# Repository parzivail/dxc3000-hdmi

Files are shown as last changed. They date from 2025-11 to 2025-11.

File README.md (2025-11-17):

# Sony DXC-3000A HDMI Conversion

This repository is split into multiple KiCad projects.

## MS9282 breakout

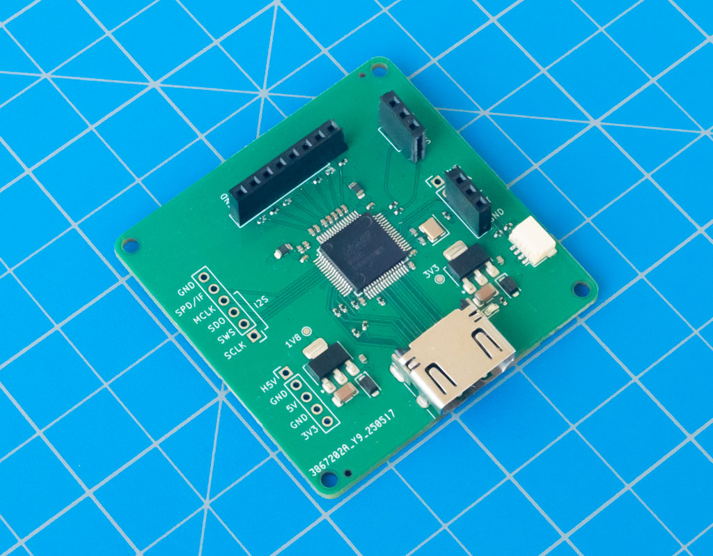
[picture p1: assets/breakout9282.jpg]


Contains the MS9282 breakout

Directory: `ms9282_carrier`

## DXC-3000A module template

Contains the blank PCB that matches the physical dimensions and 50-pin header of the backplane modules

Directory: `module_template`

## DXC-3000A module breakout

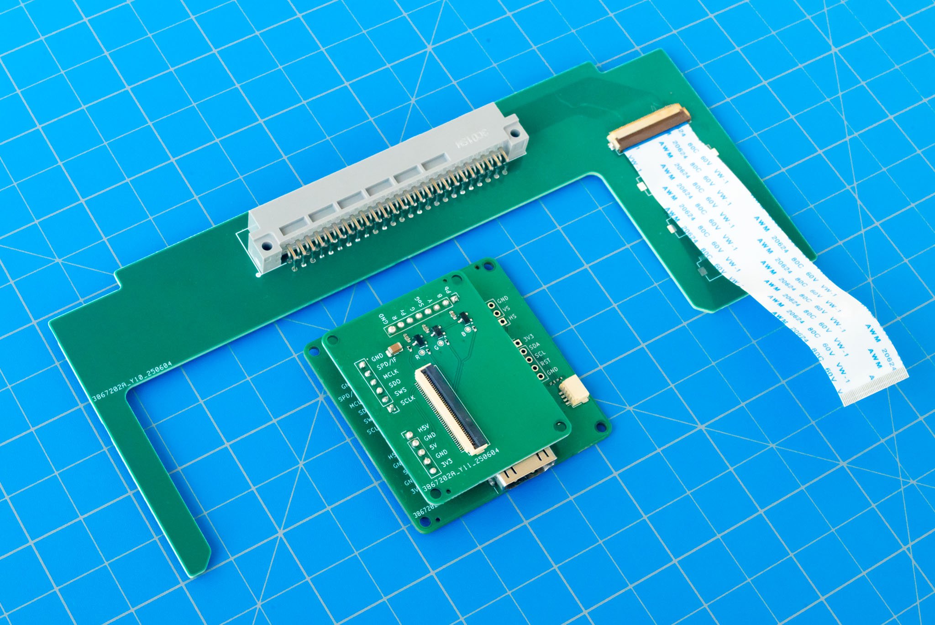
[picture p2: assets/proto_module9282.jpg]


A few assets in this image:

The DXC-3000A backplane-to-FPC breakout board
* Directory: `module_breakout`

The video conditioner "shield" for the MS9282 breakout
* Directory: `ms9282_carrier_adapter`

Pairs with the MS9282 breakout from above.

## MS9282 module

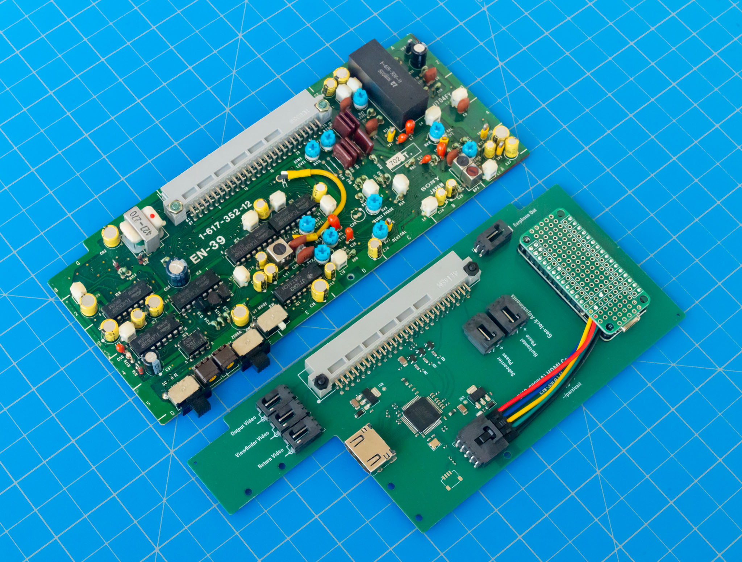
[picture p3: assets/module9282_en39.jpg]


Contains the complete MS9282-based EN-39 substitute for HDMI conversion. The image shows it in comparison with the original EN-39 module.

Directory: `ms9282_module`

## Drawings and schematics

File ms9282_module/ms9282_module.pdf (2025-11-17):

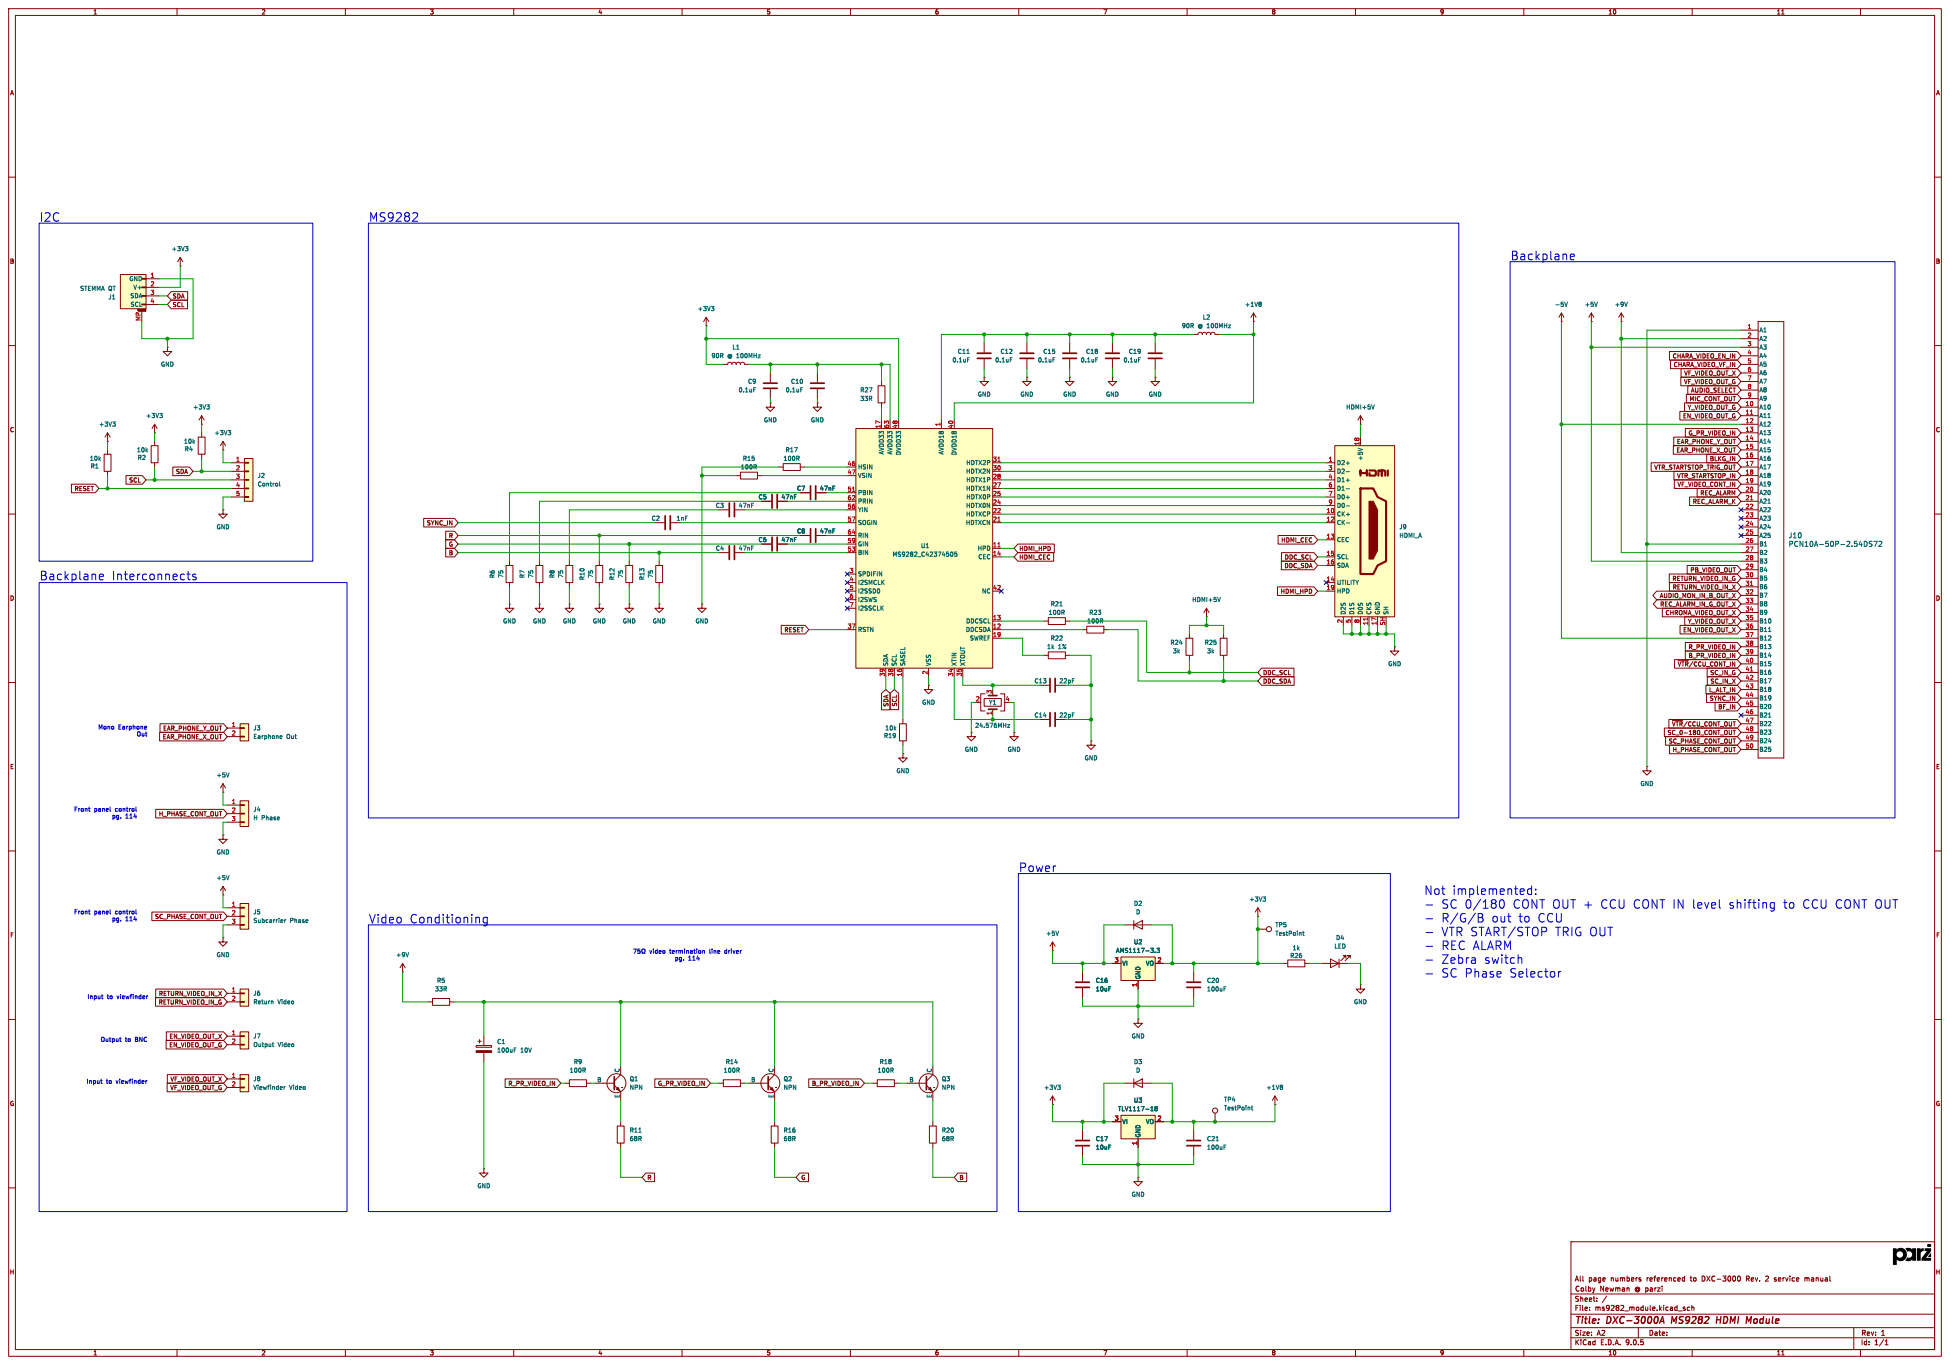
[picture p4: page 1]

1 XTIN 34 XTOUT 35 DDCSCL 13 DDCSDA 12 U1 MS9282_C42374505 C7 47nF C8 47nF R27

2 DVDD18 40 HDTX2P 31 HDTX2N 30 HDTX1P 28 HDTX1N 27 HDTX0P 25 HDTX0N 24 HDTXCP 22 HDTXCN 21 HPD 11 CEC 14 NC 42 SWREF 19 HSIN 46 VSIN 47 SOGIN 57

8 CKS 11 GND 17 SH SH

Mono Earphone Out Output to BNC

Front panel control pg. 114

- VTR START/STOP TRIG OUT
- REC ALARM
- Zebra switch
- SC Phase Selector

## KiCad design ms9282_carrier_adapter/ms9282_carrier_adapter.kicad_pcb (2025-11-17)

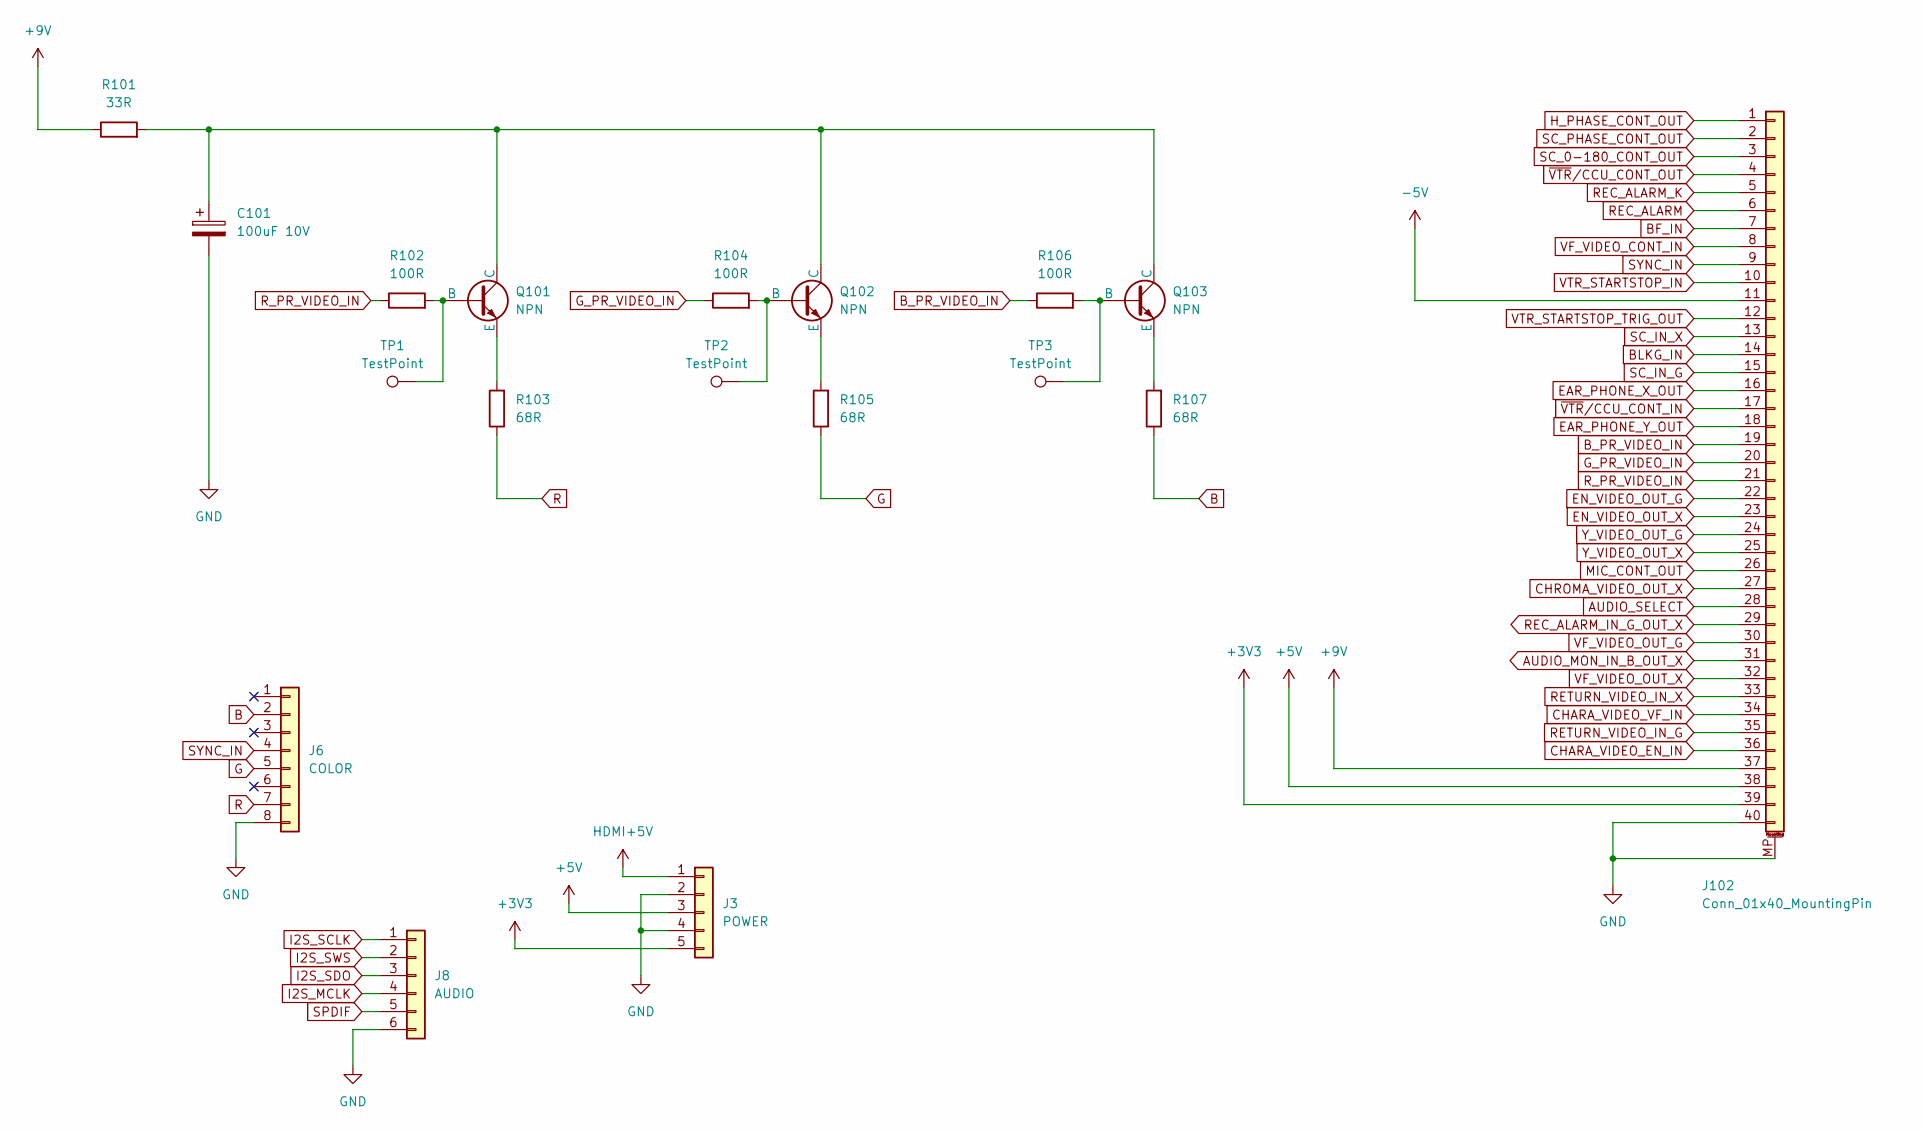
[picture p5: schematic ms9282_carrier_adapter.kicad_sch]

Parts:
C101: 100uF 10V; C_1206_3216Metric; LCSC Part C15008
J3: POWER; PinHeader_1x05_P2.54mm_Vertical
J6: COLOR; PinHeader_1x08_P2.54mm_Vertical
J8: AUDIO; PinHeader_1x06_P2.54mm_Vertical
J102: Conn_01x40_MountingPin; Hirose_FH12-40S-0.5SH_1x40-1MP_P0.50mm_Horizontal; LCSC Part C596725
Q101, Q102, Q103: NPN; SOT-23; LCSC Part C27829
R101: 33R; R_0402_1005Metric; LCSC Part C25105
R102, R104, R106: 100R; R_0402_1005Metric; LCSC Part C25076
R103, R105, R107: 68R; R_0603_1608Metric; LCSC Part C27592
TP1, TP2, TP3: TestPoint; TestPoint_Pad_D1.0mm

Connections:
+3V3: J3.5, J102.39
+5V: J3.3, J102.38
+9V: J102.37, R101.1
-5V: J102.11
AUDIO_MON_IN_B_OUT_X: J102.31
AUDIO_SELECT: J102.28
B: J6.2, R107.1
BF_IN: J102.7
BLKG_IN: J102.14
B_PR_VIDEO_IN: J102.19, R106.1
CHARA_VIDEO_EN_IN: J102.36
CHARA_VIDEO_VF_IN: J102.34
CHROMA_VIDEO_OUT_X: J102.27
EAR_PHONE_X_OUT: J102.16
EAR_PHONE_Y_OUT: J102.18
EN_VIDEO_OUT_G: J102.22
EN_VIDEO_OUT_X: J102.23
G: J6.5, R105.1
GND: C101.2, J3.2, J3.4, J6.8, J8.6, J102.40, J102.MP (MountPin)
G_PR_VIDEO_IN: J102.20, R104.1
HDMI+5V: J3.1
H_PHASE_CONT_OUT: J102.1
I2S_MCLK: J8.4
I2S_SCLK: J8.1
I2S_SDO: J8.3
I2S_SWS: J8.2
MIC_CONT_OUT: J102.26
unnamed: Q101.1 (B), R102.2, TP1.1
unnamed: C101.1, Q101.3 (C), Q102.3 (C), Q103.3 (C), R101.2
unnamed: Q101.2 (E), R103.2
unnamed: Q102.1 (B), R104.2, TP2.1
unnamed: Q102.2 (E), R105.2
unnamed: Q103.1 (B), R106.2, TP3.1
unnamed: Q103.2 (E), R107.2
R: J6.7, R103.1
REC_ALARM: J102.6
REC_ALARM_IN_G_OUT_X: J102.29
REC_ALARM_K: J102.5
RETURN_VIDEO_IN_G: J102.35
RETURN_VIDEO_IN_X: J102.33
R_PR_VIDEO_IN: J102.21, R102.1
SC_0-180_CONT_OUT: J102.3
SC_IN_G: J102.15
SC_IN_X: J102.13
SC_PHASE_CONT_OUT: J102.2
SPDIF: J8.5
SYNC_IN: J6.4, J102.9
VF_VIDEO_CONT_IN: J102.8
VF_VIDEO_OUT_G: J102.30
VF_VIDEO_OUT_X: J102.32
VTR_STARTSTOP_IN: J102.10
VTR_STARTSTOP_TRIG_OUT: J102.12
Y_VIDEO_OUT_G: J102.24
Y_VIDEO_OUT_X: J102.25
~VTR/CCU_CONT_IN: J102.17
~VTR/CCU_CONT_OUT: J102.4

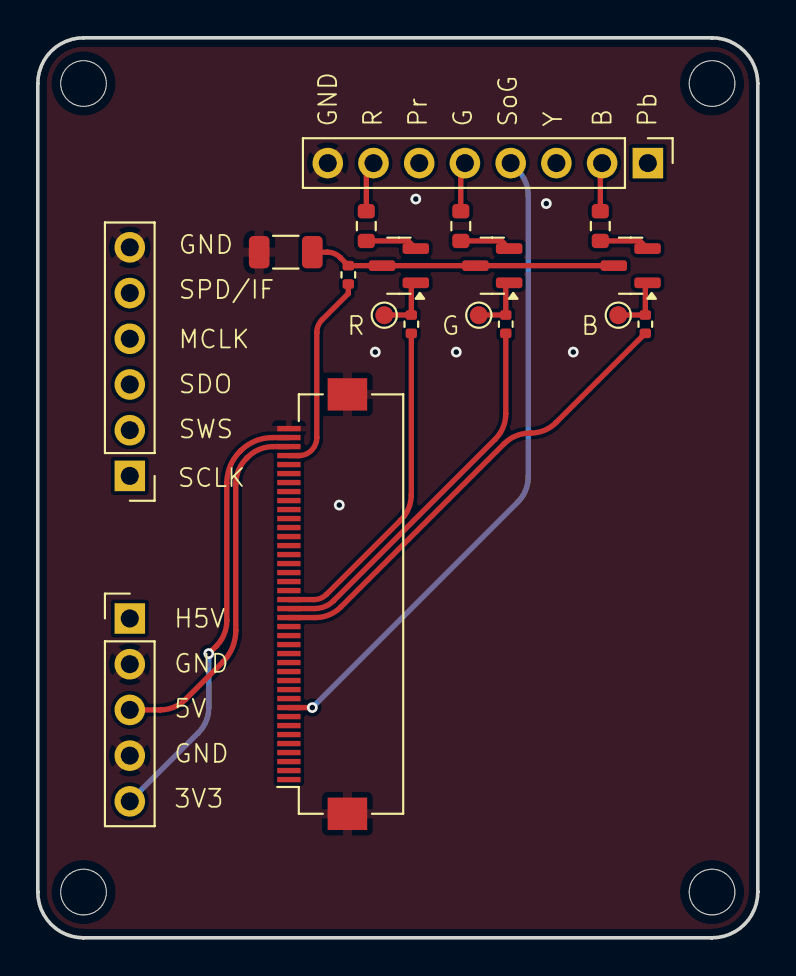
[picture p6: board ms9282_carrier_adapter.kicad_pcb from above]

Board: 2 copper layers, 40.0 x 50.0 mm, 18 parts (0 on the bottom side), 18 nets.

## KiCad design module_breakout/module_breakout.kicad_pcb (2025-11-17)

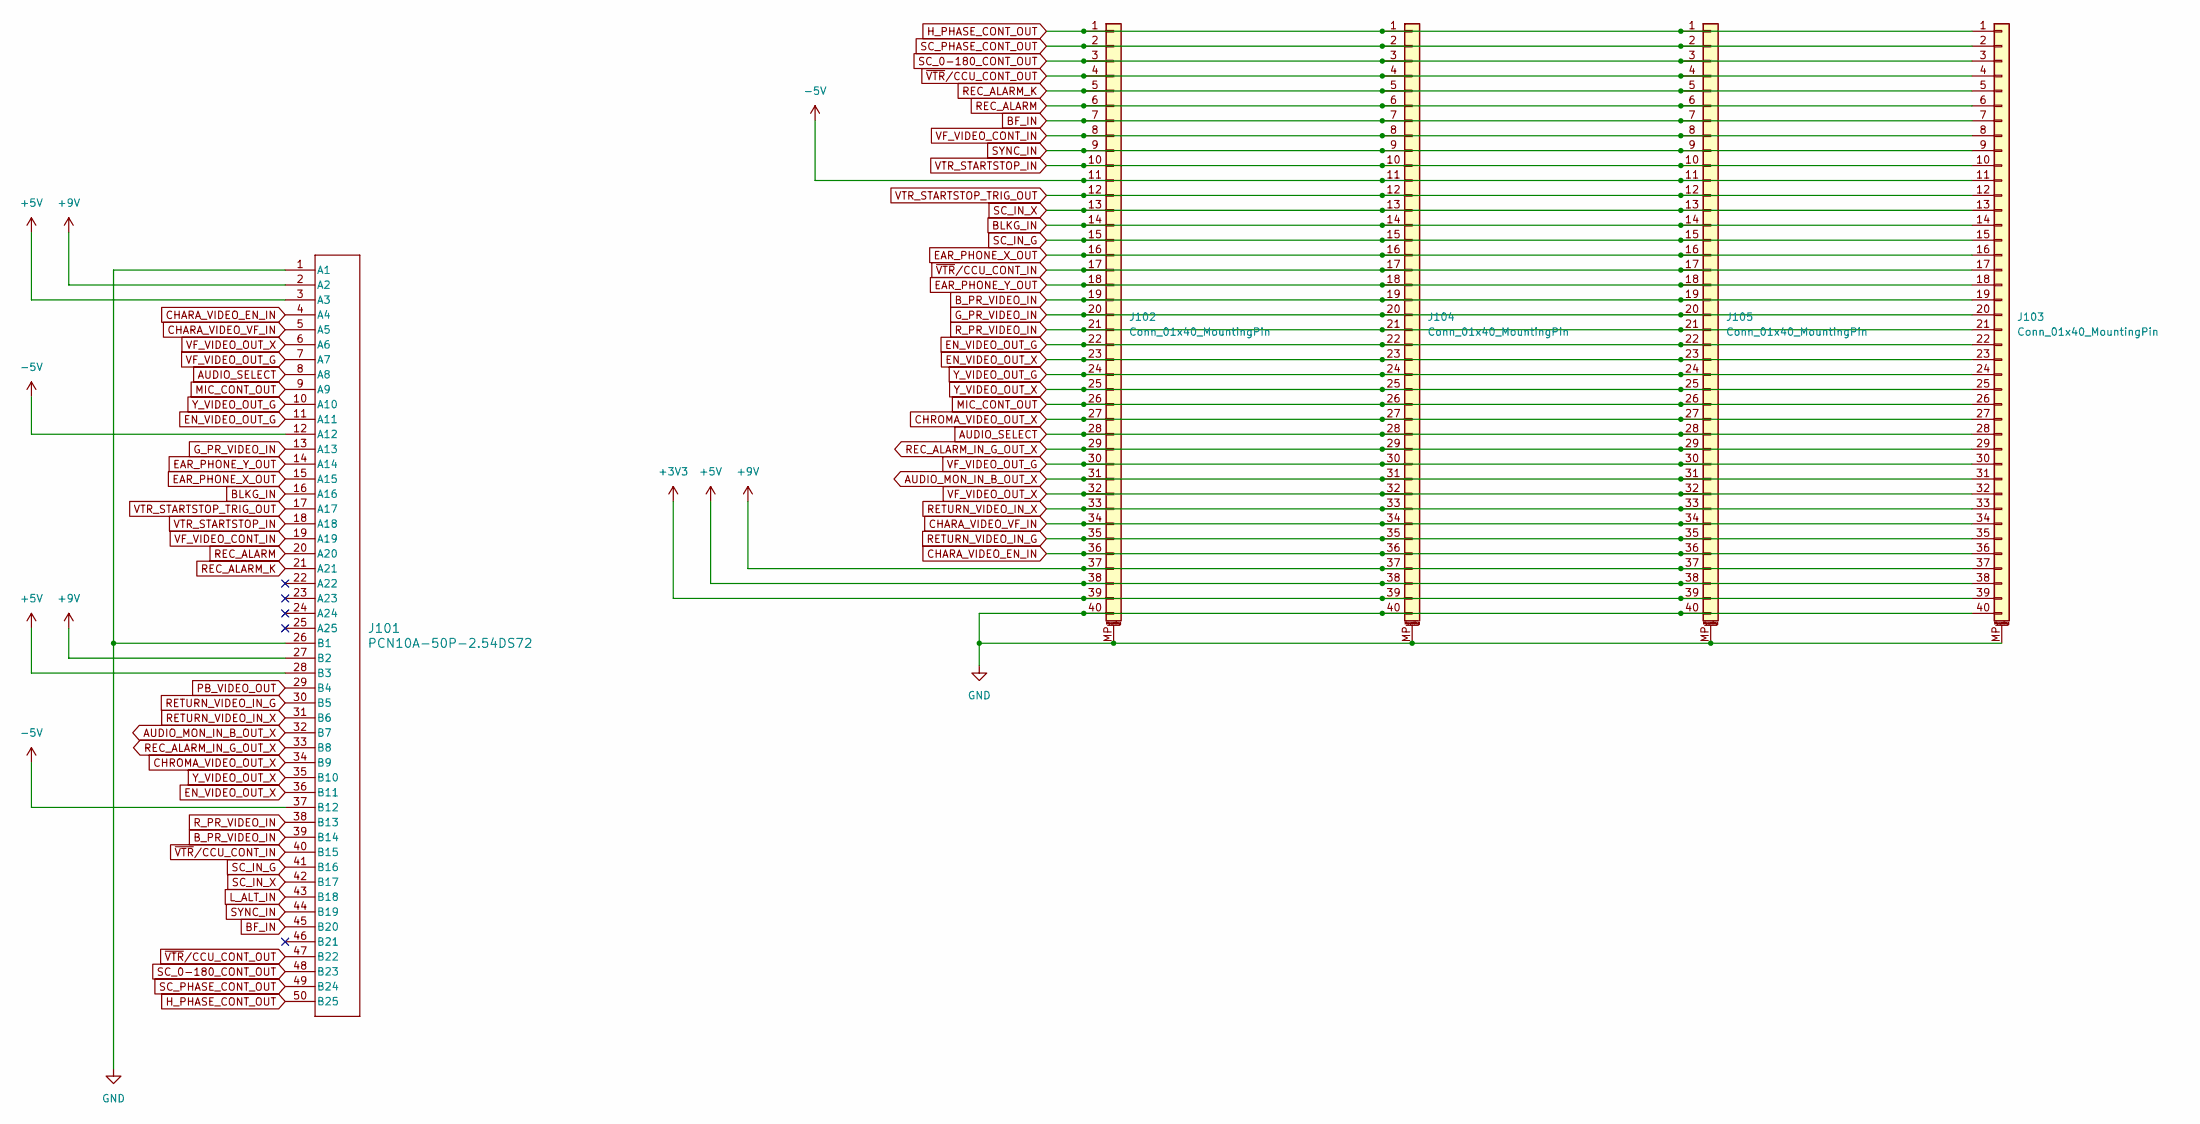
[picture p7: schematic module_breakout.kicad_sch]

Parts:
J101: PCN10A-50P-2.54DS72; CONN_PCN10A-50P_HIR
J102, J103, J104, J105: Conn_01x40_MountingPin; Hirose_FH12-40S-0.5SH_1x40-1MP_P0.50mm_Horizontal

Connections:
+3V3: J102.39, J103.39, J104.39, J105.39
+5V: J101.3 (A3), J101.28 (B3), J102.38, J103.38, J104.38, J105.38
+9V: J101.2 (A2), J101.27 (B2), J102.37, J103.37, J104.37, J105.37
-5V: J101.12 (A12), J101.37 (B12), J102.11, J103.11, J104.11, J105.11
AUDIO_MON_IN_B_OUT_X: J101.32 (B7), J102.31, J103.31, J104.31, J105.31
AUDIO_SELECT: J101.8 (A8), J102.28, J103.28, J104.28, J105.28
BF_IN: J101.45 (B20), J102.7, J103.7, J104.7, J105.7
BLKG_IN: J101.16 (A16), J102.14, J103.14, J104.14, J105.14
B_PR_VIDEO_IN: J101.39 (B14), J102.19, J103.19, J104.19, J105.19
CHARA_VIDEO_EN_IN: J101.4 (A4), J102.36, J103.36, J104.36, J105.36
CHARA_VIDEO_VF_IN: J101.5 (A5), J102.34, J103.34, J104.34, J105.34
CHROMA_VIDEO_OUT_X: J101.34 (B9), J102.27, J103.27, J104.27, J105.27
EAR_PHONE_X_OUT: J101.15 (A15), J102.16, J103.16, J104.16, J105.16
EAR_PHONE_Y_OUT: J101.14 (A14), J102.18, J103.18, J104.18, J105.18
EN_VIDEO_OUT_G: J101.11 (A11), J102.22, J103.22, J104.22, J105.22
EN_VIDEO_OUT_X: J101.36 (B11), J102.23, J103.23, J104.23, J105.23
GND: J101.1 (A1), J101.26 (B1), J102.40, J102.MP (MountPin), J103.40, J103.MP (MountPin), J104.40, J104.MP (MountPin), J105.40, J105.MP (MountPin)
G_PR_VIDEO_IN: J101.13 (A13), J102.20, J103.20, J104.20, J105.20
H_PHASE_CONT_OUT: J101.50 (B25), J102.1, J103.1, J104.1, J105.1
L_ALT_IN: J101.43 (B18)
MIC_CONT_OUT: J101.9 (A9), J102.26, J103.26, J104.26, J105.26
PB_VIDEO_OUT: J101.29 (B4)
REC_ALARM: J101.20 (A20), J102.6, J103.6, J104.6, J105.6
REC_ALARM_IN_G_OUT_X: J101.33 (B8), J102.29, J103.29, J104.29, J105.29
REC_ALARM_K: J101.21 (A21), J102.5, J103.5, J104.5, J105.5
RETURN_VIDEO_IN_G: J101.30 (B5), J102.35, J103.35, J104.35, J105.35
RETURN_VIDEO_IN_X: J101.31 (B6), J102.33, J103.33, J104.33, J105.33
R_PR_VIDEO_IN: J101.38 (B13), J102.21, J103.21, J104.21, J105.21
SC_0-180_CONT_OUT: J101.48 (B23), J102.3, J103.3, J104.3, J105.3
SC_IN_G: J101.41 (B16), J102.15, J103.15, J104.15, J105.15
SC_IN_X: J101.42 (B17), J102.13, J103.13, J104.13, J105.13
SC_PHASE_CONT_OUT: J101.49 (B24), J102.2, J103.2, J104.2, J105.2
SYNC_IN: J101.44 (B19), J102.9, J103.9, J104.9, J105.9
VF_VIDEO_CONT_IN: J101.19 (A19), J102.8, J103.8, J104.8, J105.8
VF_VIDEO_OUT_G: J101.7 (A7), J102.30, J103.30, J104.30, J105.30
VF_VIDEO_OUT_X: J101.6 (A6), J102.32, J103.32, J104.32, J105.32
VTR_STARTSTOP_IN: J101.18 (A18), J102.10, J103.10, J104.10, J105.10
VTR_STARTSTOP_TRIG_OUT: J101.17 (A17), J102.12, J103.12, J104.12, J105.12
Y_VIDEO_OUT_G: J101.10 (A10), J102.24, J103.24, J104.24, J105.24
Y_VIDEO_OUT_X: J101.35 (B10), J102.25, J103.25, J104.25, J105.25
~VTR/CCU_CONT_IN: J101.40 (B15), J102.17, J103.17, J104.17, J105.17
~VTR/CCU_CONT_OUT: J101.47 (B22), J102.4, J103.4, J104.4, J105.4

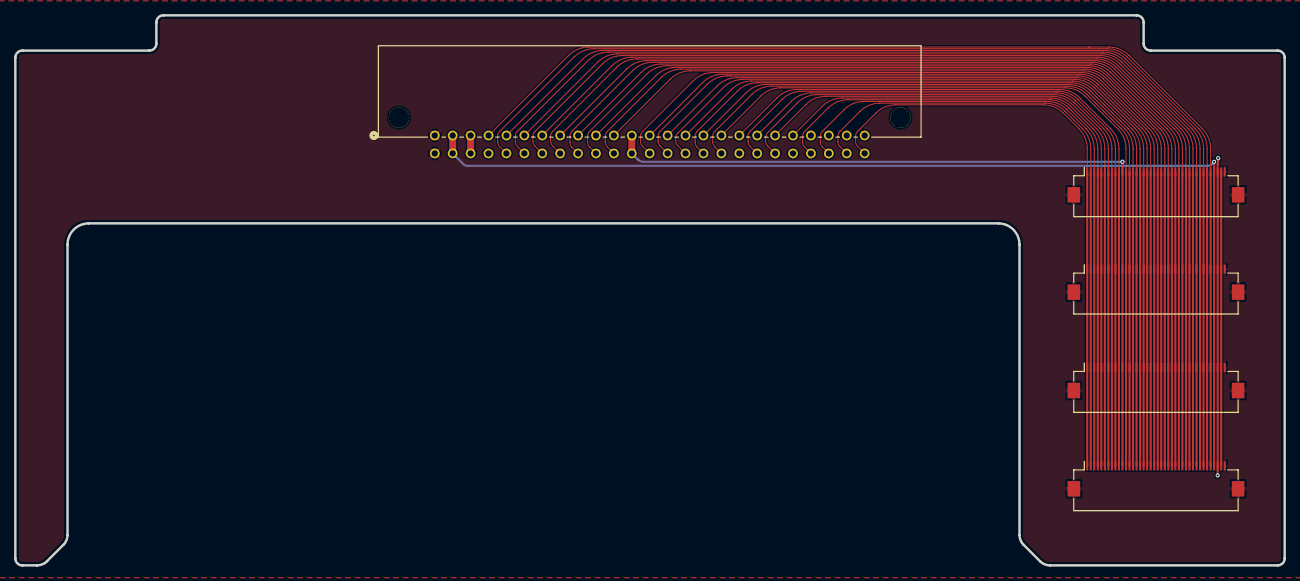
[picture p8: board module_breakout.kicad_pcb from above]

Board: 2 copper layers, 180.0 x 78.0 mm, 5 parts (0 on the bottom side), 40 nets.

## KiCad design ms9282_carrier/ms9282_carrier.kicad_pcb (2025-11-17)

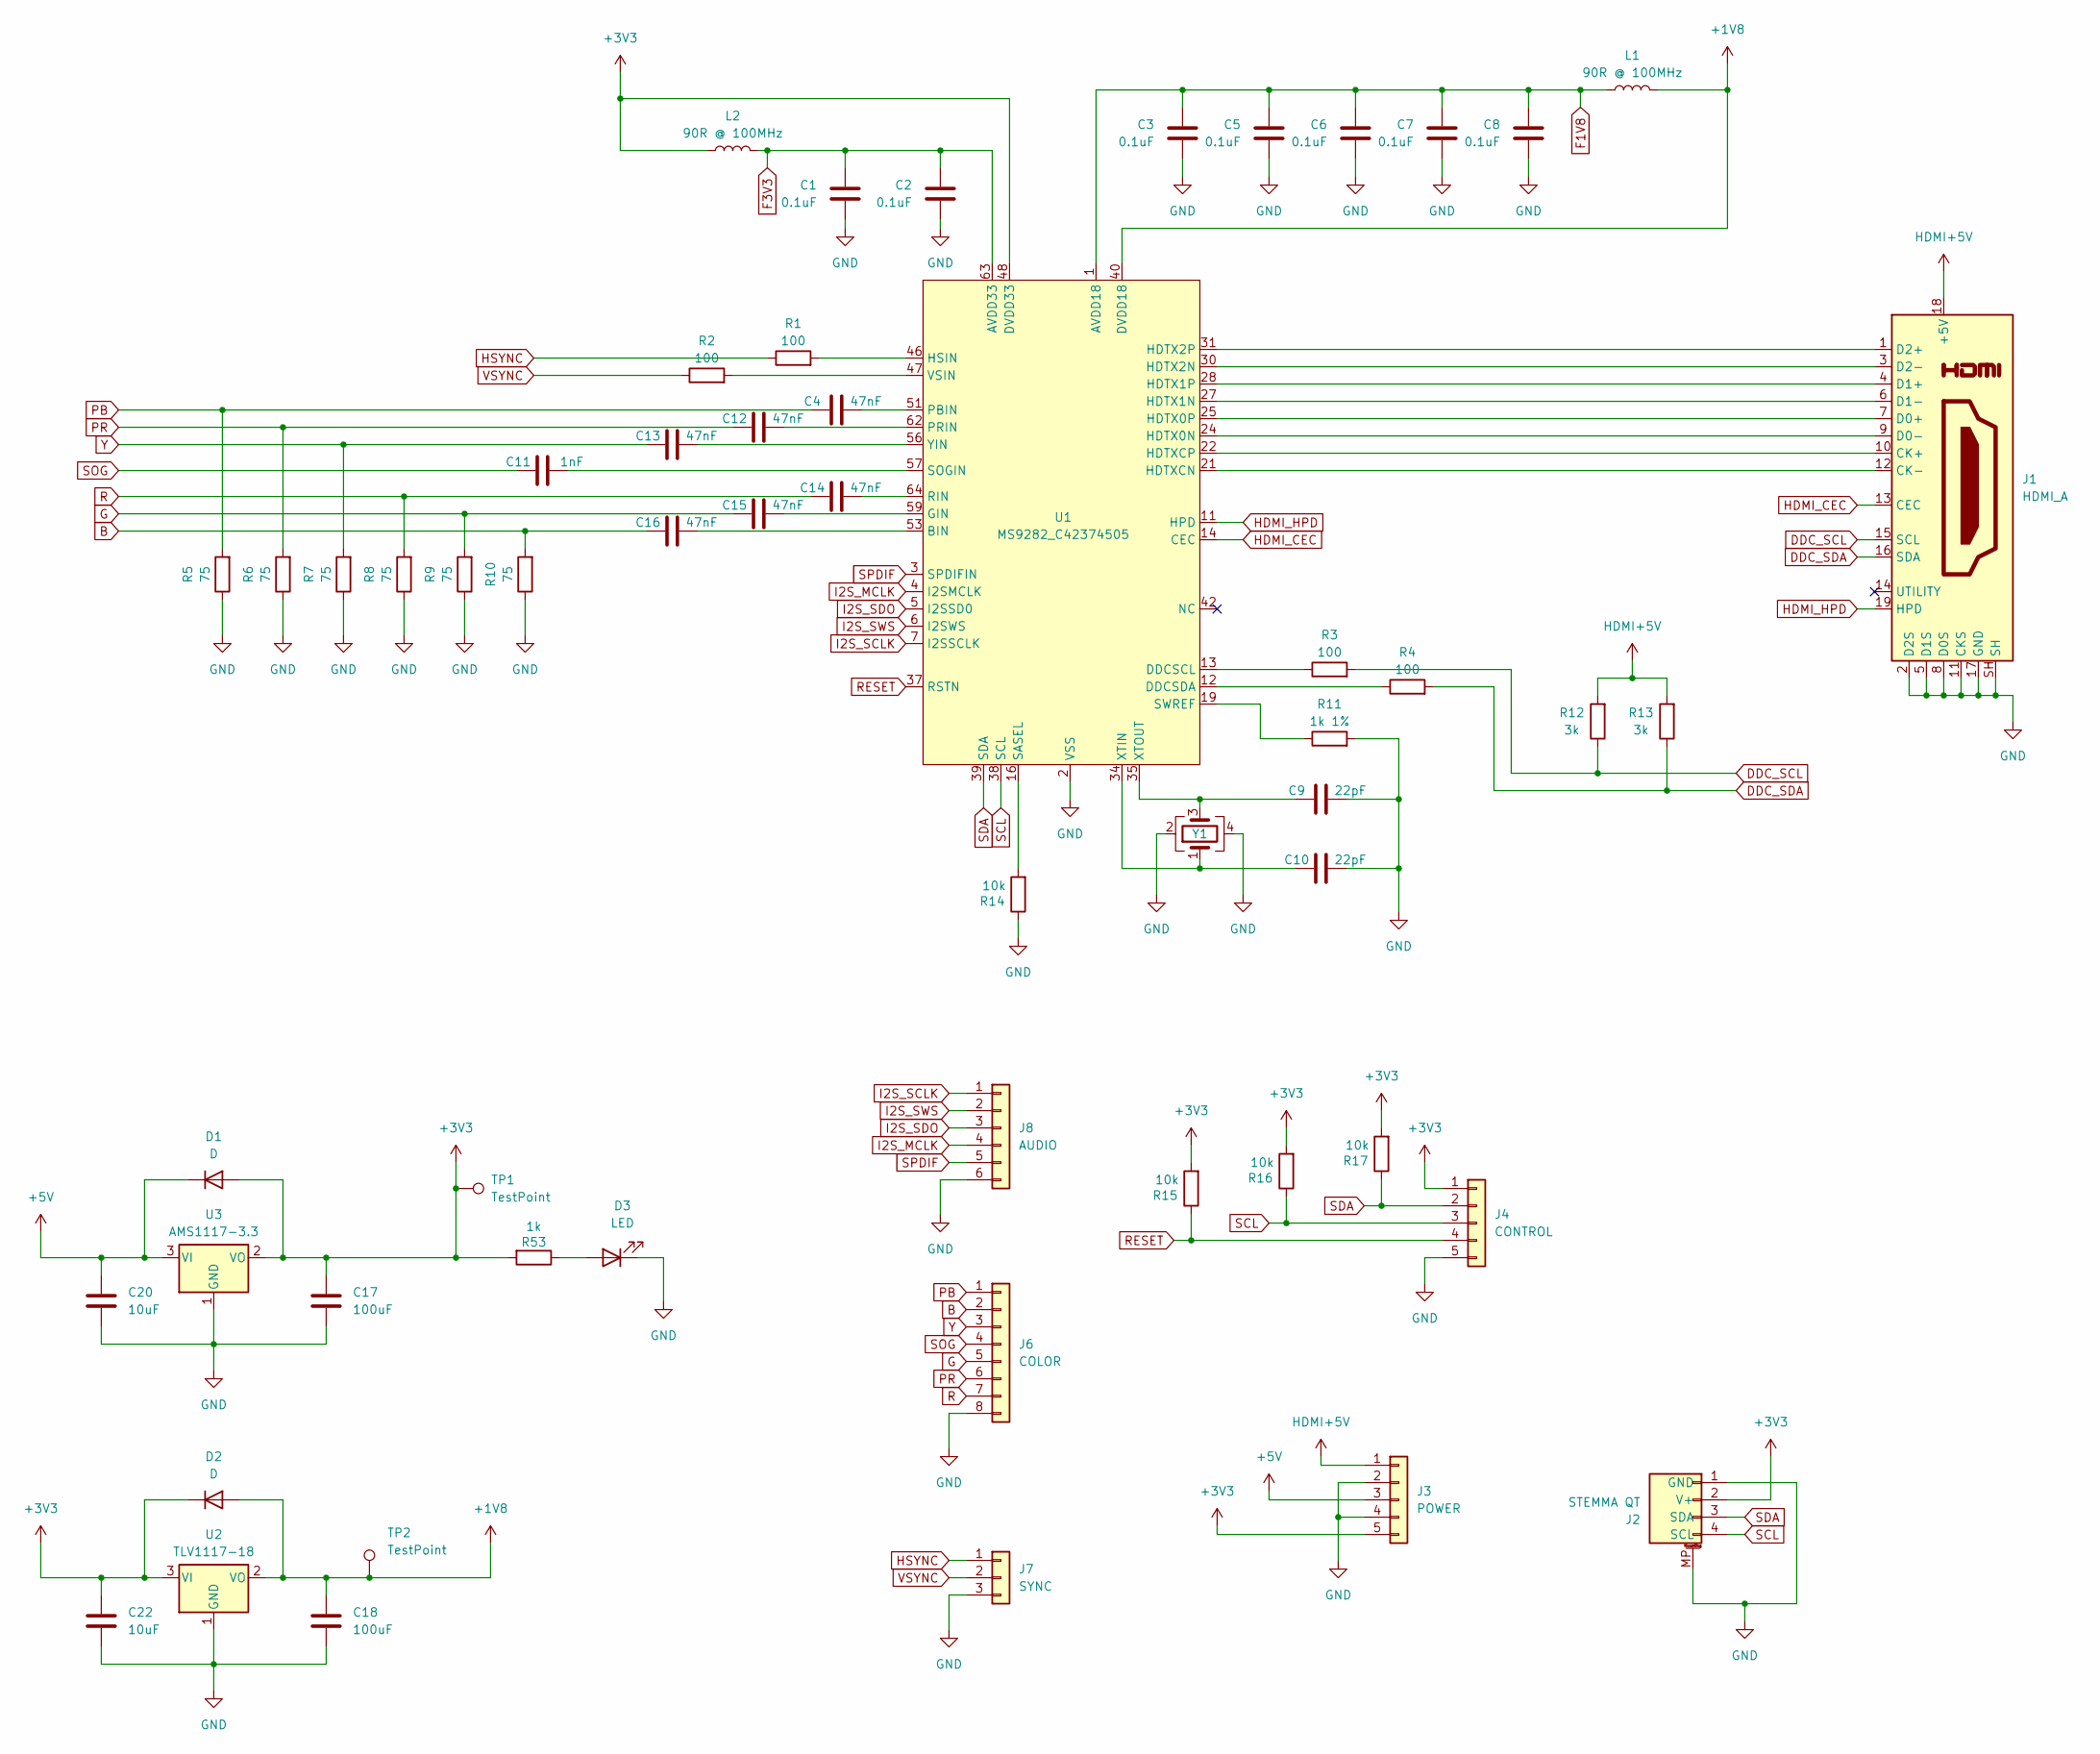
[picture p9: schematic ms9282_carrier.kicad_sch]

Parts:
C1, C2, C3, C5, C6, C7, C8: 0.1uF; C_0402_1005Metric; LCSC Part C1525
C4, C12, C13, C14, C15, C16: 47nF; C_0402_1005Metric; LCSC Part C307434
C9, C10: 22pF; C_0402_1005Metric; LCSC Part C1555
C11: 1nF; C_0402_1005Metric; LCSC Part C1523
C17, C18: 100uF; C_1206_3216Metric; LCSC Part C15008
C20, C22: 10uF; C_0402_1005Metric; LCSC Part C15525
D1, D2: D; D_SOD-123F; LCSC Part C64898
D3: LED; LED_0603_1608Metric; LCSC Part C2286
J1: HDMI_A; HDMI_A_Molex_208658-1001_Horizontal; LCSC Part C2858275
J2: STEMMA QT; JST_SH_SM04B-SRSS-TB_1x04-1MP_P1.00mm_Horizontal; LCSC Part C160404
J3: POWER; PinHeader_1x05_P2.54mm_Vertical
J4: CONTROL; PinHeader_1x05_P2.54mm_Vertical
J6: COLOR; PinHeader_1x08_P2.54mm_Vertical
J7: SYNC; PinHeader_1x03_P2.54mm_Vertical
J8: AUDIO; PinHeader_1x06_P2.54mm_Vertical
L1, L2: 90R @ 100MHz; L_0805_2012Metric; LCSC Part C1015
R1, R2, R3, R4: 100; R_0402_1005Metric; LCSC Part C25076
R5, R6, R7, R8, R9, R10: 75; R_0402_1005Metric; LCSC Part C25133
R11: 1k 1%; R_0402_1005Metric; LCSC Part C11702
R12, R13: 3k; R_0402_1005Metric; LCSC Part C25890
R14, R15, R16, R17: 10k; R_0402_1005Metric; LCSC Part C25744
R53: 1k; R_0402_1005Metric; LCSC Part C11702
TP1, TP2: TestPoint; TestPoint_Pad_D1.0mm
U1: MS9282_C42374505; LQFP-64_L10.0-W10.0-P0.50-LS12.0-BL; LCSC Part C42374505
U2: TLV1117-18; SOT-223-3_TabPin2; LCSC Part C2862410
U3: AMS1117-3.3; SOT-223-3_TabPin2; LCSC Part C6186
Y1: Crystal_GND24; Crystal_SMD_3225-4Pin_3.2x2.5mm; LCSC Part C654993

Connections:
+1V8: C18.1, D2.2 (A), L1.2, TP2.1, U1.9 (DVDD18), U1.40 (DVDD18), U2.2 (VO)
+3V3: C17.1, C22.1, D1.2 (A), D2.1 (K), J2.2 (V+), J3.5, J4.1, L2.1, R15.2, R16.2, R17.2, R53.2, TP1.1, U1.15 (DVDD33), U1.33 (DVDD33), U1.48 (DVDD33), U2.3 (VI), U3.2 (VO)
+5V: C20.1, D1.1 (K), J3.3, U3.3 (VI)
B: C16.2, J6.2, R10.2
DDC_SCL: J1.15 (SCL), R3.2, R12.1
DDC_SDA: J1.16 (SDA), R4.2, R13.1
F1V8: C3.1, C5.1, C6.1, C7.1, C8.1, L1.1, U1.1 (AVDD18), U1.23 (AVDD18), U1.29 (AVDD18), U1.55 (AVDD18), U1.61 (AVDD18)
F3V3: C1.1, C2.1, L2.2, U1.17 (AVDD33), U1.49 (AVDD33), U1.52 (AVDD33), U1.58 (AVDD33), U1.63 (AVDD33)
G: C15.2, J6.5, R9.2
GND: C1.2, C2.2, C3.2, C5.2, C6.2, C7.2, C8.2, C9.1, C10.1, C17.2, C18.2, C20.2, C22.2, D3.1 (K), J1.2 (D2S), J1.5 (D1S), J1.8 (D0S), J1.11 (CKS), J1.17 (GND), J1.SH, J2.1 (GND), J2.MP, J3.2, J3.4, J4.5, J6.8, J7.3, J8.6, R5.1, R6.1, R7.1, R8.1, R9.1, R10.1, R11.2, R14.1, U1.2 (VSS), U1.8 (VSS), U1.10 (VSS), U1.18 (VSS), U1.20 (VSS), U1.26 (VSS), U1.32 (VSS), U1.36 (VSS), U1.41 (VSS), U1.45 (VSS), U1.50 (VSS), U1.54 (VSS), U1.60 (VSS), U2.1 (GND), U3.1 (GND), Y1.2, Y1.4
HDMI+5V: J1.18 (+5V), J3.1, R12.2, R13.2
HDMI_CEC: J1.13 (CEC), U1.14 (CEC)
HDMI_HPD: J1.19 (HPD), U1.11 (HPD)
HSYNC: J7.1, R1.1
I2S_MCLK: J8.4, U1.4 (I2SMCLK)
I2S_SCLK: J8.1, U1.7 (I2SSCLK)
I2S_SDO: J8.3, U1.5 (I2SSD0)
I2S_SWS: J8.2, U1.6 (I2SWS)
unnamed: D3.2 (A), R53.1
unnamed: J1.10 (CK+), U1.22 (HDTXCP)
unnamed: J1.12 (CK-), U1.21 (HDTXCN)
unnamed: J1.7 (D0+), U1.25 (HDTX0P)
unnamed: J1.9 (D0-), U1.24 (HDTX0N)
unnamed: J1.4 (D1+), U1.28 (HDTX1P)
unnamed: J1.6 (D1-), U1.27 (HDTX1N)
unnamed: J1.1 (D2+), U1.31 (HDTX2P)
unnamed: J1.3 (D2-), U1.30 (HDTX2N)
unnamed: C16.1, U1.53 (BIN)
unnamed: R3.1, U1.13 (DDCSCL)
unnamed: R4.1, U1.12 (DDCSDA)
unnamed: C15.1, U1.59 (GIN)
unnamed: R1.2, U1.46 (HSIN)
unnamed: C4.1, U1.51 (PBIN)
unnamed: C12.1, U1.62 (PRIN)
unnamed: C14.1, U1.64 (RIN)
unnamed: R14.2, U1.16 (SASEL)
unnamed: C11.1, U1.57 (SOGIN)
unnamed: R11.1, U1.19 (SWREF)
unnamed: R2.2, U1.47 (VSIN)
unnamed: C10.2, U1.34 (XTIN), Y1.1
unnamed: C9.2, U1.35 (XTOUT), Y1.3
unnamed: C13.1, U1.56 (YIN)
PB: C4.2, J6.1, R5.2
PR: C12.2, J6.6, R6.2
R: C14.2, J6.7, R8.2
RESET: J4.4, R15.1, U1.37 (RSTN)
SCL: J2.4 (SCL), J4.3, R16.1, U1.38 (SCL)
SDA: J2.3 (SDA), J4.2, R17.1, U1.39 (SDA)
SOG: C11.2, J6.4
SPDIF: J8.5, U1.3 (SPDIFIN)
VSYNC: J7.2, R2.1
Y: C13.2, J6.3, R7.2

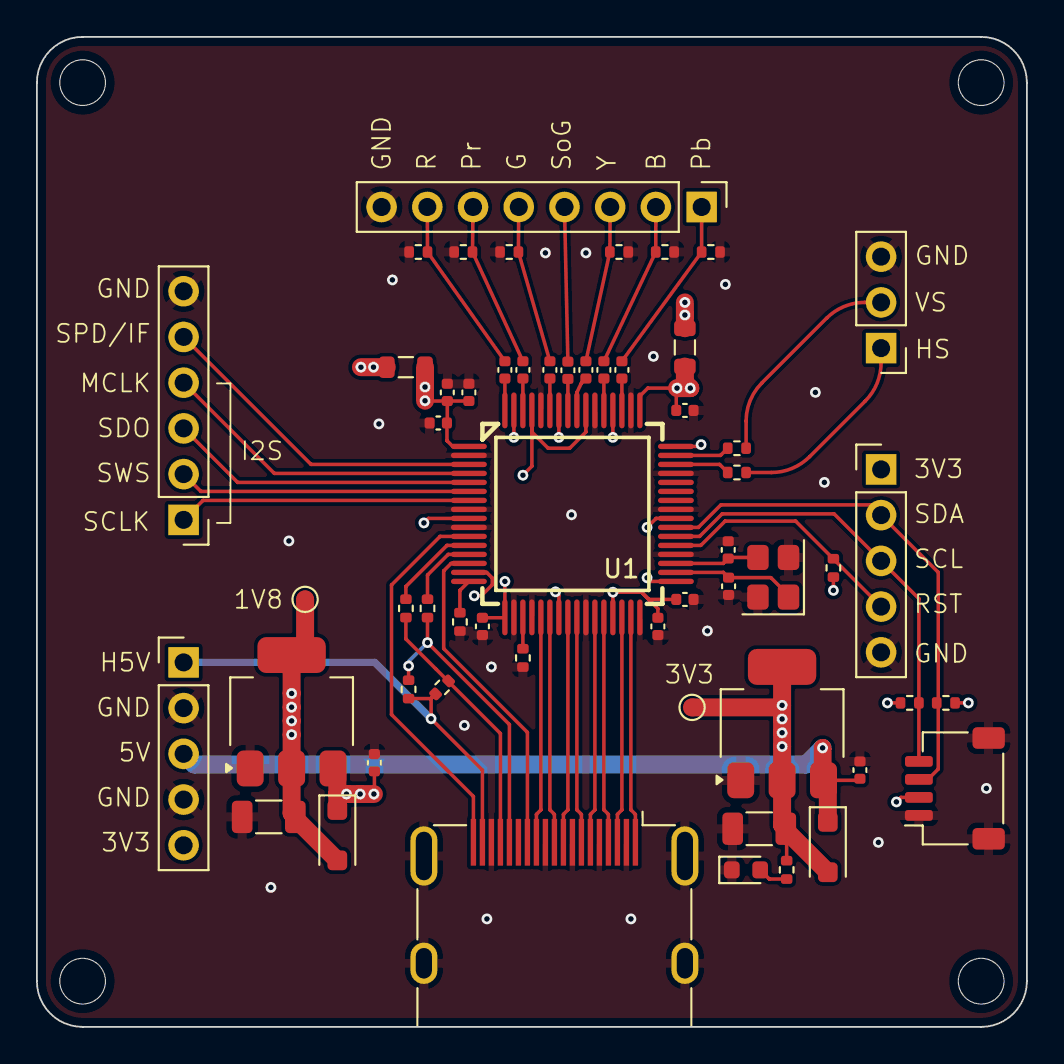
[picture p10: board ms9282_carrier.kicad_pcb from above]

Board: 4 copper layers, 55.0 x 55.0 mm, 56 parts (0 on the bottom side), 52 nets.

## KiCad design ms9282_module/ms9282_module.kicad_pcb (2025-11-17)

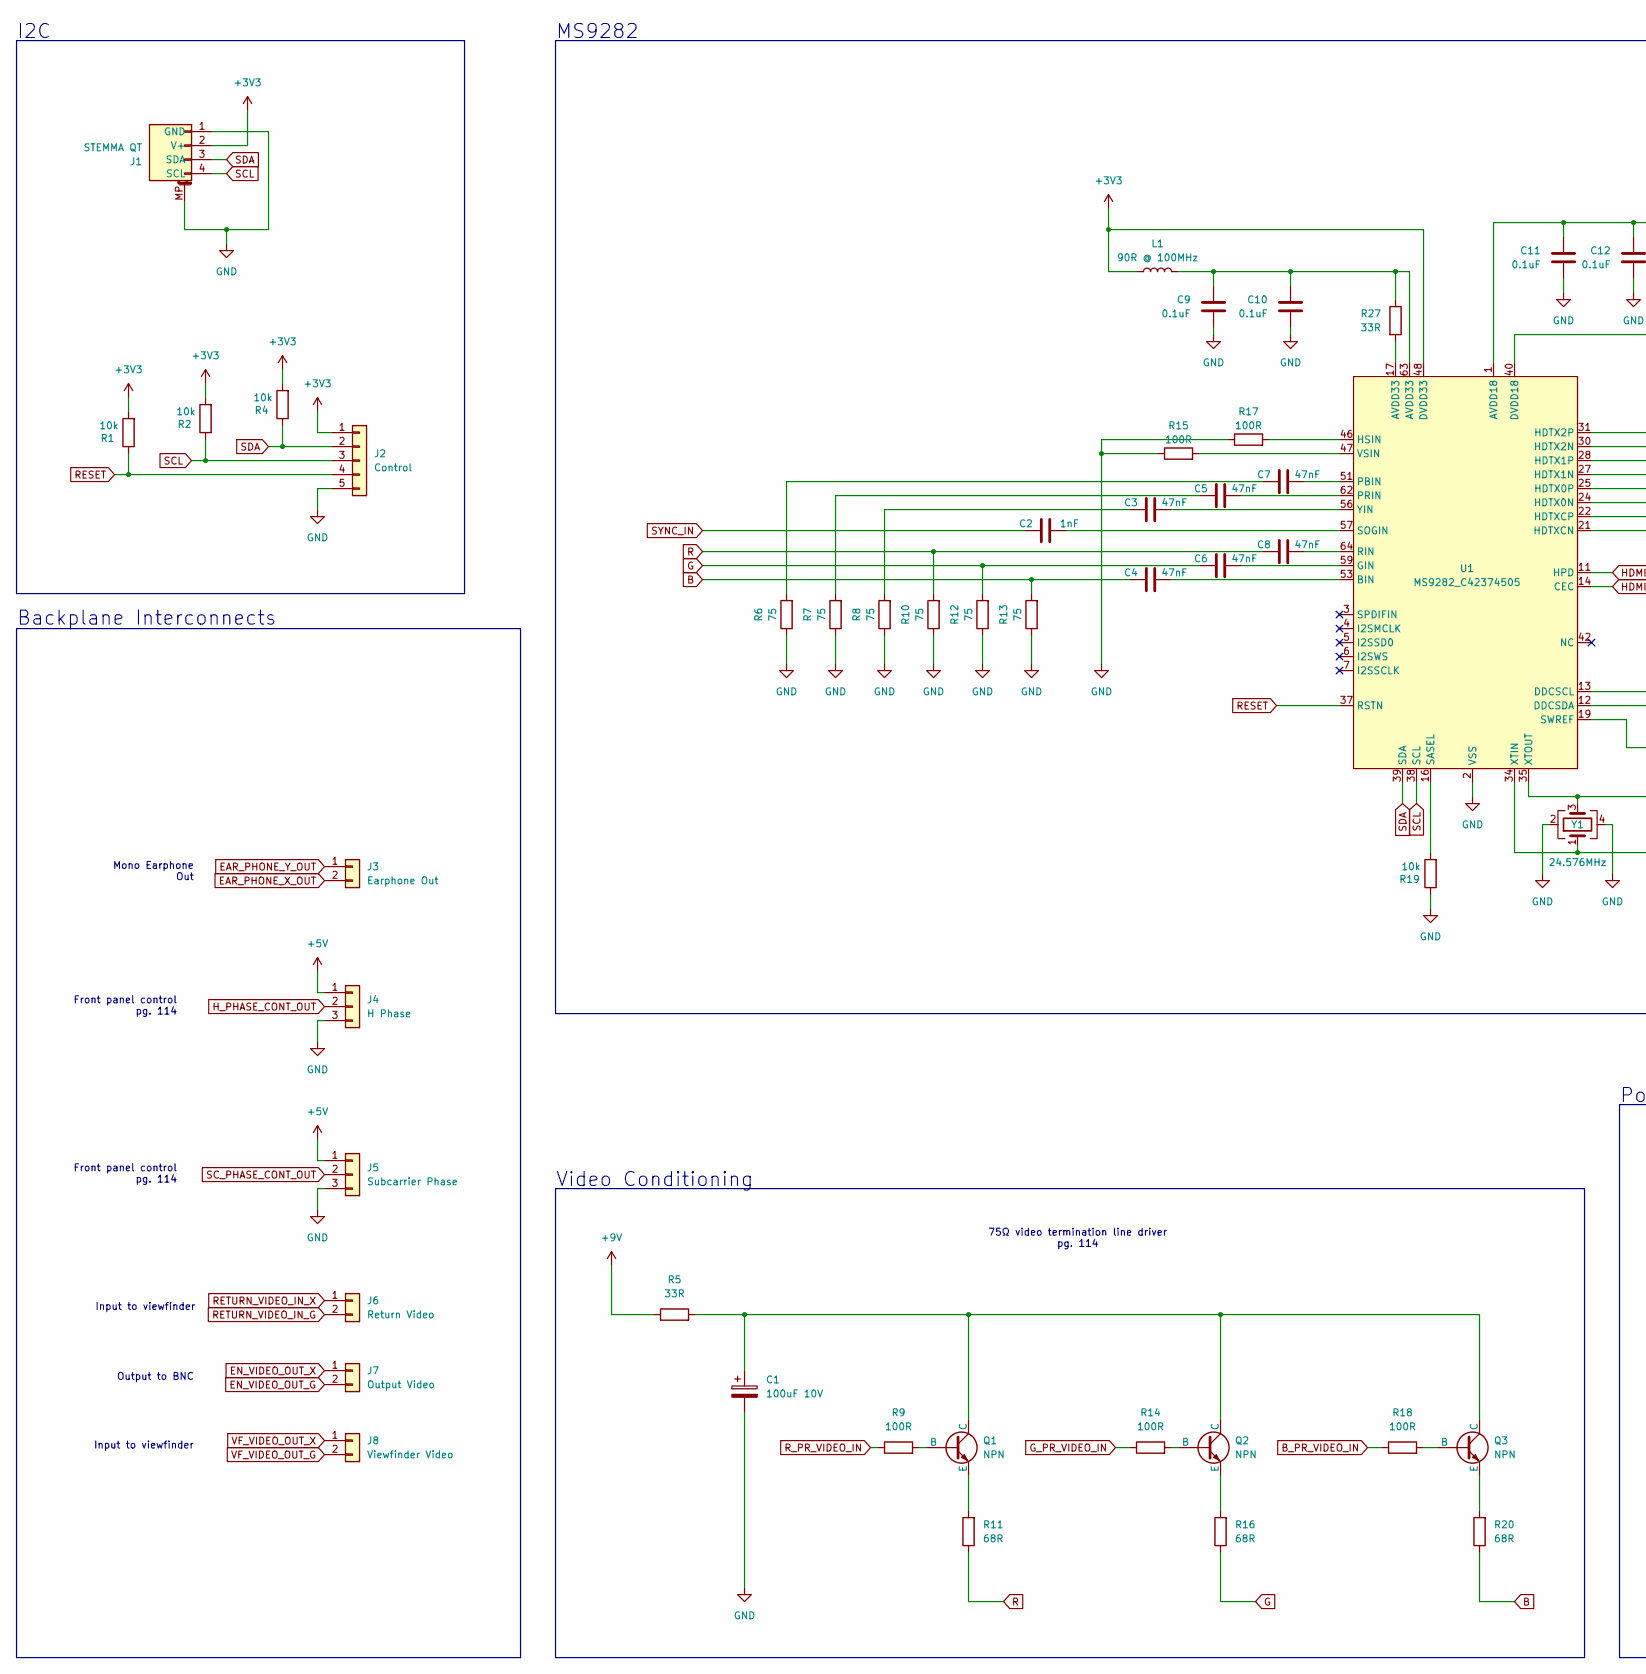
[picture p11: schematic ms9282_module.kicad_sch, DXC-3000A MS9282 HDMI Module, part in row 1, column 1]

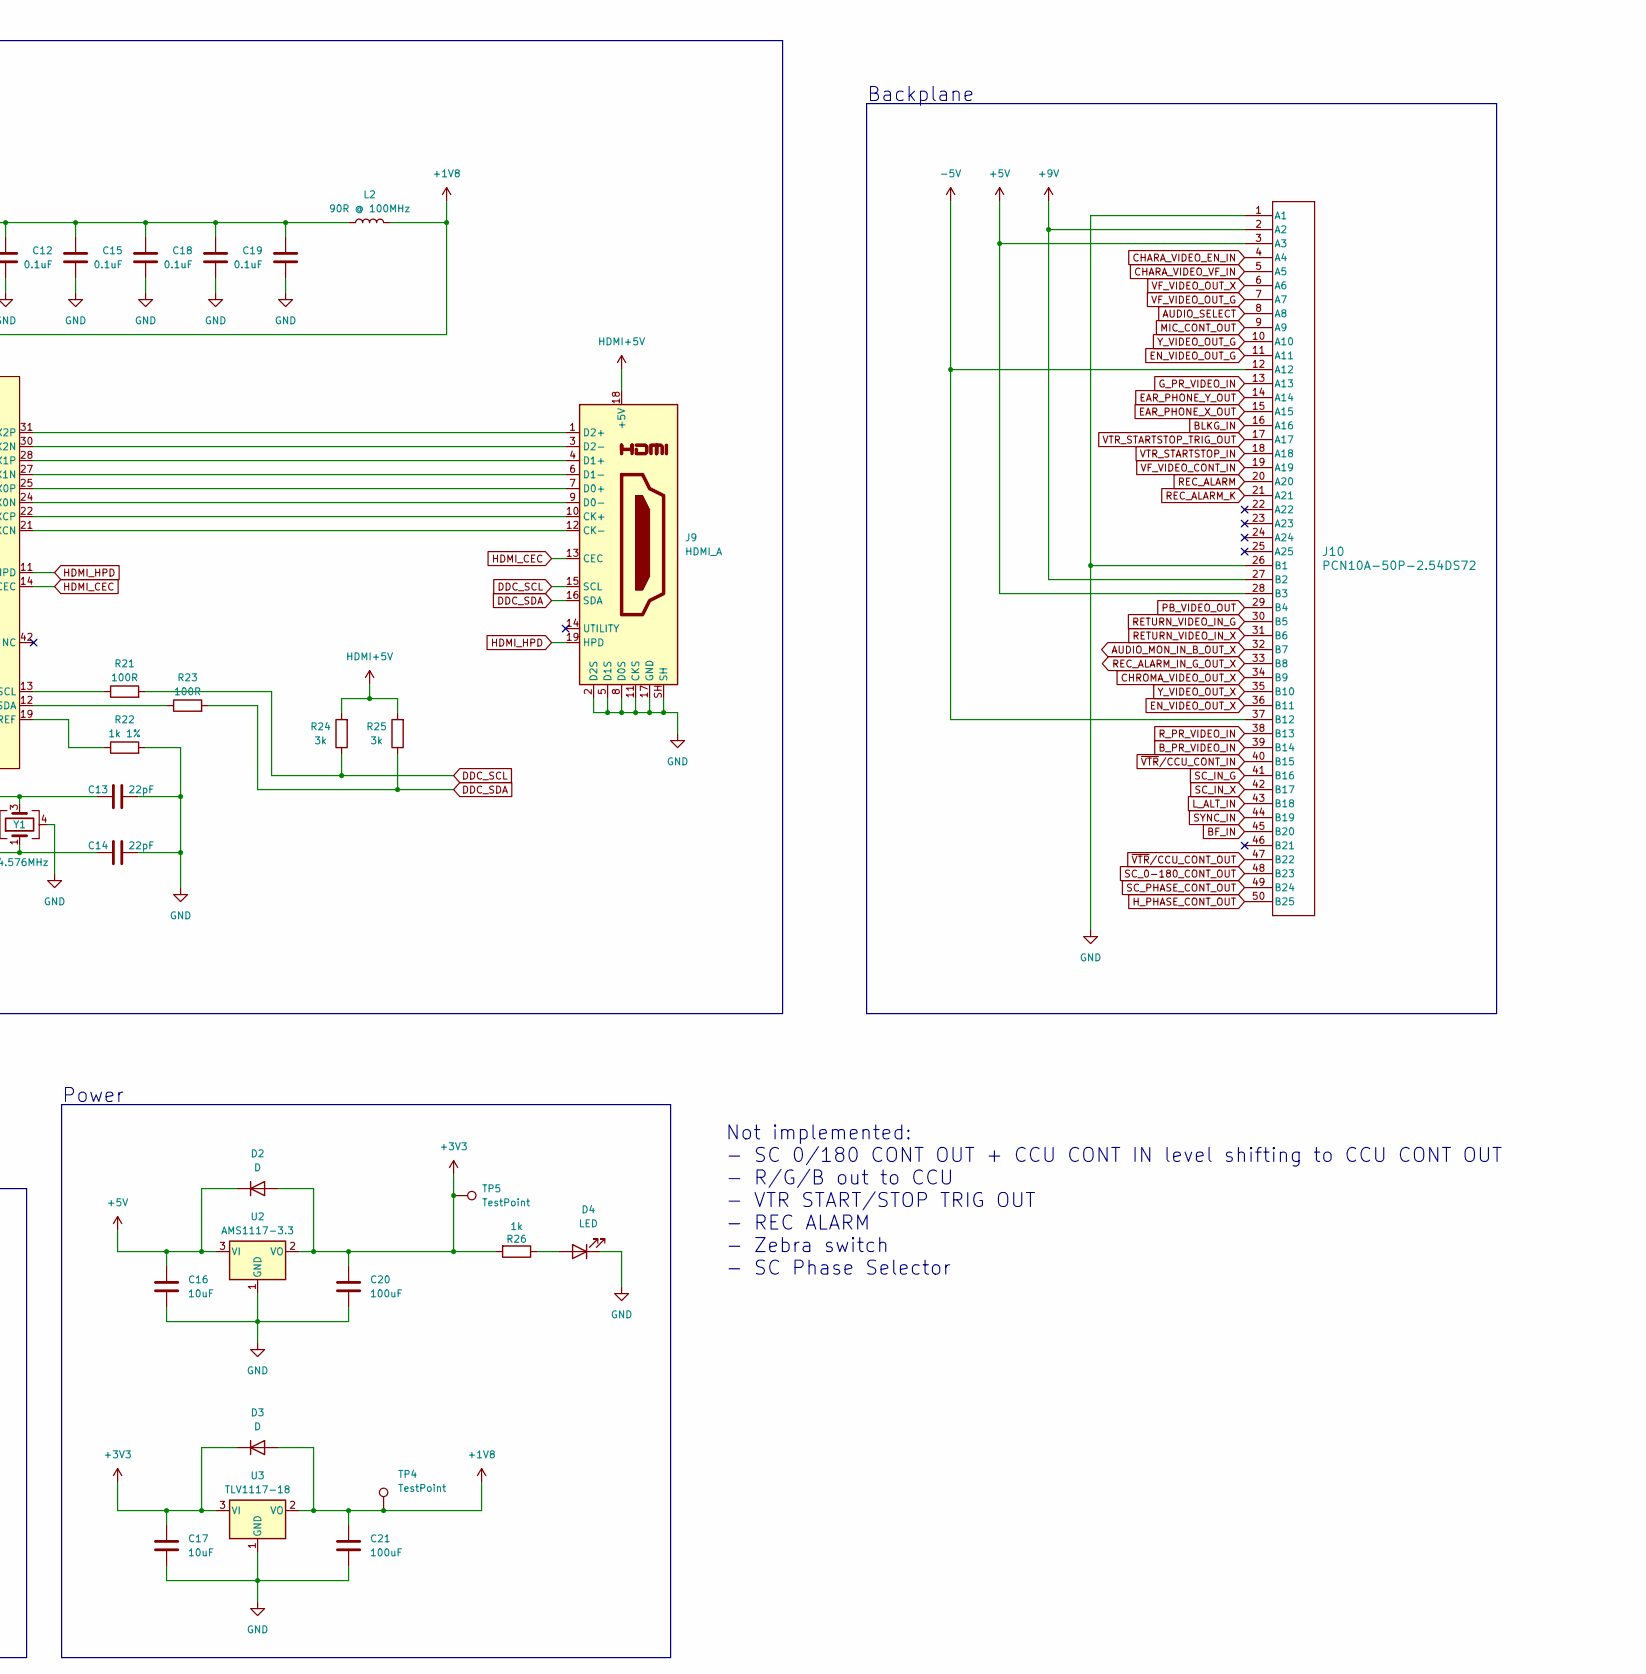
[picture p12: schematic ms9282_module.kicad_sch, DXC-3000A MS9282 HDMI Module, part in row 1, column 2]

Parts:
C1: 100uF 10V; C_1206_3216Metric; LCSC Part C15008
C2: 1nF; C_0402_1005Metric; LCSC Part C1523
C3, C4, C5, C6, C7, C8: 47nF; C_0402_1005Metric; LCSC Part C307434
C9, C10, C11, C12, C15, C18, C19: 0.1uF; C_0402_1005Metric; LCSC Part C1525
C13, C14: 22pF; C_0402_1005Metric; LCSC Part C1555
C16, C17: 10uF; C_0402_1005Metric; LCSC Part C15525
C20, C21: 100uF; C_1206_3216Metric; LCSC Part C15008
D2, D3: D; D_SOD-123F; LCSC Part C64898
D4: LED; LED_0603_1608Metric; LCSC Part C2286
J1: STEMMA QT; JST_SH_SM04B-SRSS-TB_1x04-1MP_P1.00mm_Horizontal; LCSC Part C160404
J2: Control; PinHeader_1x05_P2.54mm_Horizontal
J3: Earphone Out; PinHeader_1x02_P2.54mm_Horizontal
J4: H Phase; PinHeader_1x03_P2.54mm_Horizontal
J5: Subcarrier Phase; PinHeader_1x03_P2.54mm_Horizontal
J6: Return Video; PinHeader_1x02_P2.54mm_Horizontal
J7: Output Video; PinHeader_1x02_P2.54mm_Horizontal
J8: Viewfinder Video; PinHeader_1x02_P2.54mm_Horizontal
J9: HDMI_A; HDMI_A_Molex_208658-1001_Horizontal; LCSC Part C2858275
J10: PCN10A-50P-2.54DS72; CONN_PCN10A-50P_HIR
L1, L2: 90R @ 100MHz; L_0805_2012Metric; LCSC Part C1015
Q1, Q2, Q3: NPN; SOT-23; LCSC Part C27829
R1, R2, R4, R19: 10k; R_0402_1005Metric; LCSC Part C25744
R5, R27: 33R; R_0402_1005Metric; LCSC Part C25105
R6, R7, R8, R10, R12, R13: 75; R_0402_1005Metric; LCSC Part C25133
R9, R14, R15, R17, R18, R21, R23: 100R; R_0402_1005Metric; LCSC Part C25076
R11, R16, R20: 68R; R_0603_1608Metric; LCSC Part C27592
R22: 1k 1%; R_0402_1005Metric; LCSC Part C11702
R24, R25: 3k; R_0402_1005Metric; LCSC Part C25890
R26: 1k; R_0402_1005Metric; LCSC Part C11702
TP4, TP5: TestPoint; TestPoint_Pad_D1.0mm
U1: MS9282_C42374505; LQFP-64_L10.0-W10.0-P0.50-LS12.0-BL; LCSC Part C42374505
U2: AMS1117-3.3; SOT-223-3_TabPin2; LCSC Part C6186
U3: TLV1117-18; SOT-223-3_TabPin2; LCSC Part C2862410
Y1: 24.576MHz; Crystal_SMD_3225-4Pin_3.2x2.5mm; LCSC Part C654993

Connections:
+1V8: C21.1, D3.2 (A), L2.2, TP4.1, U1.9 (DVDD18), U1.40 (DVDD18), U3.2 (VO)
+3V3: C17.1, C20.1, D2.2 (A), D3.1 (K), J1.2 (V+), J2.1, L1.1, R1.2, R2.2, R4.2, R26.2, TP5.1, U1.15 (DVDD33), U1.33 (DVDD33), U1.48 (DVDD33), U2.2 (VO), U3.3 (VI)
+5V: C16.1, D2.1 (K), J4.1, J5.1, J10.3 (A3), J10.28 (B3), U2.3 (VI)
+9V: J10.2 (A2), J10.27 (B2), R5.1
-5V: J10.12 (A12), J10.37 (B12)
AUDIO_MON_IN_B_OUT_X: J10.32 (B7)
AUDIO_SELECT: J10.8 (A8)
B: C4.2, R13.2, R20.1
BF_IN: J10.45 (B20)
BLKG_IN: J10.16 (A16)
B_PR_VIDEO_IN: J10.39 (B14), R18.1
CHARA_VIDEO_EN_IN: J10.4 (A4)
CHARA_VIDEO_VF_IN: J10.5 (A5)
CHROMA_VIDEO_OUT_X: J10.34 (B9)
DDC_SCL: J9.15 (SCL), R21.2, R24.1
DDC_SDA: J9.16 (SDA), R23.2, R25.1
EAR_PHONE_X_OUT: J3.2, J10.15 (A15)
EAR_PHONE_Y_OUT: J3.1, J10.14 (A14)
EN_VIDEO_OUT_G: J7.2, J10.11 (A11)
EN_VIDEO_OUT_X: J7.1, J10.36 (B11)
G: C6.2, R12.2, R16.1
GND: C1.2, C9.2, C10.2, C11.2, C12.2, C13.1, C14.1, C15.2, C16.2, C17.2, C18.2, C19.2, C20.2, C21.2, D4.1 (K), J1.1 (GND), J1.MP, J2.5, J4.3, J5.3, J9.2 (D2S), J9.5 (D1S), J9.8 (D0S), J9.11 (CKS), J9.17 (GND), J9.SH, J10.1 (A1), J10.26 (B1), R6.1, R7.1, R8.1, R10.1, R12.1, R13.1, R15.1, R17.1, R19.1, R22.2, U1.2 (VSS), U1.8 (VSS), U1.10 (VSS), U1.18 (VSS), U1.20 (VSS), U1.26 (VSS), U1.32 (VSS), U1.36 (VSS), U1.41 (VSS), U1.45 (VSS), U1.50 (VSS), U1.54 (VSS), U1.60 (VSS), U2.1 (GND), U3.1 (GND), Y1.2, Y1.4
G_PR_VIDEO_IN: J10.13 (A13), R14.1
HDMI+5V: J9.18 (+5V), R24.2, R25.2
HDMI_CEC: J9.13 (CEC), U1.14 (CEC)
HDMI_HPD: J9.19 (HPD), U1.11 (HPD)
H_PHASE_CONT_OUT: J4.2, J10.50 (B25)
L_ALT_IN: J10.43 (B18)
MIC_CONT_OUT: J10.9 (A9)
unnamed: C3.2, R8.2
unnamed: C5.2, R7.2
unnamed: C7.2, R6.2
unnamed: C9.1, C10.1, L1.2, R27.1, U1.49 (AVDD33), U1.52 (AVDD33), U1.58 (AVDD33), U1.63 (AVDD33)
unnamed: C11.1, C12.1, C15.1, C18.1, C19.1, L2.1, U1.1 (AVDD18), U1.23 (AVDD18), U1.29 (AVDD18), U1.55 (AVDD18), U1.61 (AVDD18)
unnamed: D4.2 (A), R26.1
unnamed: J9.10 (CK+), U1.22 (HDTXCP)
unnamed: J9.12 (CK-), U1.21 (HDTXCN)
unnamed: J9.7 (D0+), U1.25 (HDTX0P)
unnamed: J9.9 (D0-), U1.24 (HDTX0N)
unnamed: J9.4 (D1+), U1.28 (HDTX1P)
unnamed: J9.6 (D1-), U1.27 (HDTX1N)
unnamed: J9.1 (D2+), U1.31 (HDTX2P)
unnamed: J9.3 (D2-), U1.30 (HDTX2N)
unnamed: Q1.1 (B), R9.2
unnamed: C1.1, Q1.3 (C), Q2.3 (C), Q3.3 (C), R5.2
unnamed: Q1.2 (E), R11.2
unnamed: Q2.1 (B), R14.2
unnamed: Q2.2 (E), R16.2
unnamed: Q3.1 (B), R18.2
unnamed: Q3.2 (E), R20.2
unnamed: R27.2, U1.17 (AVDD33)
unnamed: C4.1, U1.53 (BIN)
unnamed: R21.1, U1.13 (DDCSCL)
unnamed: R23.1, U1.12 (DDCSDA)
unnamed: C6.1, U1.59 (GIN)
unnamed: R17.2, U1.46 (HSIN)
unnamed: C7.1, U1.51 (PBIN)
unnamed: C5.1, U1.62 (PRIN)
unnamed: C8.1, U1.64 (RIN)
unnamed: R19.2, U1.16 (SASEL)
unnamed: C2.1, U1.57 (SOGIN)
unnamed: R22.1, U1.19 (SWREF)
unnamed: R15.2, U1.47 (VSIN)
unnamed: C14.2, U1.34 (XTIN), Y1.1
unnamed: C13.2, U1.35 (XTOUT), Y1.3
unnamed: C3.1, U1.56 (YIN)
PB_VIDEO_OUT: J10.29 (B4)
R: C8.2, R10.2, R11.1
REC_ALARM: J10.20 (A20)
REC_ALARM_IN_G_OUT_X: J10.33 (B8)
REC_ALARM_K: J10.21 (A21)
RESET: J2.4, R1.1, U1.37 (RSTN)
RETURN_VIDEO_IN_G: J6.2, J10.30 (B5)
RETURN_VIDEO_IN_X: J6.1, J10.31 (B6)
R_PR_VIDEO_IN: J10.38 (B13), R9.1
SCL: J1.4 (SCL), J2.3, R2.1, U1.38 (SCL)
SC_0-180_CONT_OUT: J10.48 (B23)
SC_IN_G: J10.41 (B16)
SC_IN_X: J10.42 (B17)
SC_PHASE_CONT_OUT: J5.2, J10.49 (B24)
SDA: J1.3 (SDA), J2.2, R4.1, U1.39 (SDA)
SYNC_IN: C2.2, J10.44 (B19)
VF_VIDEO_CONT_IN: J10.19 (A19)
VF_VIDEO_OUT_G: J8.2, J10.7 (A7)
VF_VIDEO_OUT_X: J8.1, J10.6 (A6)
VTR_STARTSTOP_IN: J10.18 (A18)
VTR_STARTSTOP_TRIG_OUT: J10.17 (A17)
Y_VIDEO_OUT_G: J10.10 (A10)
Y_VIDEO_OUT_X: J10.35 (B10)
~VTR/CCU_CONT_IN: J10.40 (B15)
~VTR/CCU_CONT_OUT: J10.47 (B22)

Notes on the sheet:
75Ω video termination line driver pg. 114
Input to viewfinder
Front panel control pg. 114
MS9282
Backplane Interconnects
Video Conditioning
I2C
Power
Mono Earphone Out
Not implemented: - SC 0/180 CONT OUT + CCU CONT IN level shifting to CCU CONT OUT - R/G/B out to CCU - VTR START/STOP TRIG OUT - REC ALARM - Zebra switch - SC Phase Selector
Backplane
Output to BNC

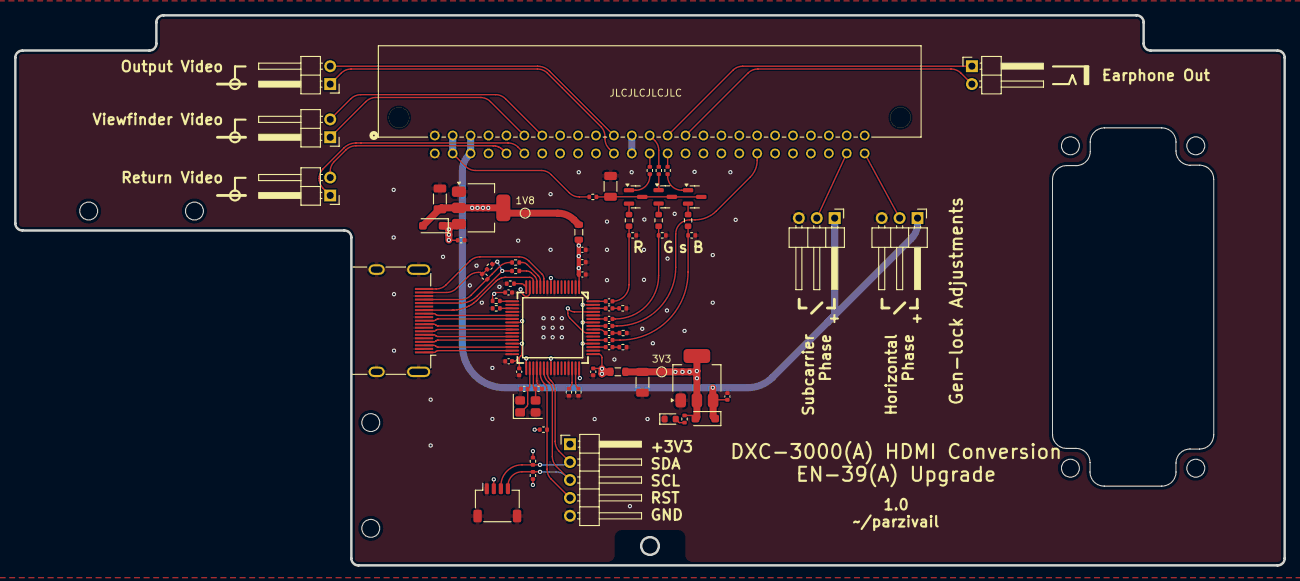
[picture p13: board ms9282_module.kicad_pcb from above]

Board: 4 copper layers, 180.0 x 78.0 mm, 71 parts (0 on the bottom side), 68 nets.
